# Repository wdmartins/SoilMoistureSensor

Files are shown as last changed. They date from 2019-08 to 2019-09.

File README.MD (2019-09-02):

# Soil Moisture Sensor

This project is aimed to measure vegetable garden soil moisture.

## Features

* MQTT enable: Reports mositure levels using MQTT.

* Deep Sleep: The controllers enters deep sleep mode and wakes up every hour to measure and report the soil mositure. The reporting is done only if the soil moisture show a large change compared to previous measurements or if 4 hours period had elapsed. This reduces power comsumption and allows the device to run on a 18650 3000mAh for up to 2 weeks.

* OTA: Over the air update is enabled by default. In order to do an OTA update, the device shall be awake. Send the following MQTT command so it remains awake the next time it wakes up so OTA can be done:

Topic: /home-assistant/moist/A/request
Payload: 'a'

## Schemmatic

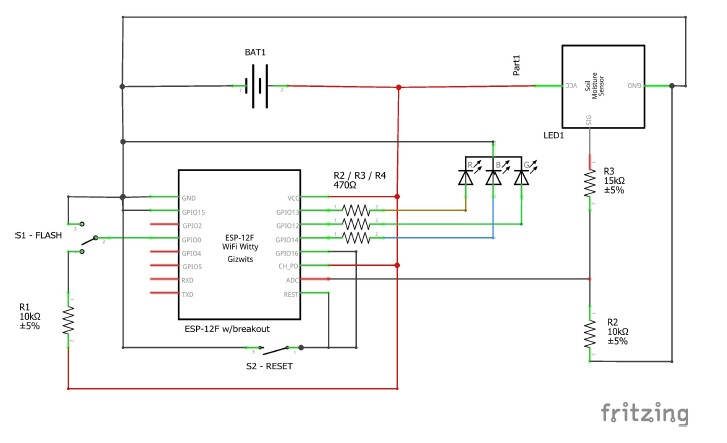
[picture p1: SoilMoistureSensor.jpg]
Soil Moisture Sensor Schemmatics


## Notes

In order to build this software add a file named secret.h at ./include and define the following constant strings:

const char * MQTT_BROKER_ADDRESS = "mqtt-server-address-or-fqdn";

const char * MQTT_USERNAME = "mqtt-user-name";

const char * MQTT_PASSWORD = "mqtt-user-password";

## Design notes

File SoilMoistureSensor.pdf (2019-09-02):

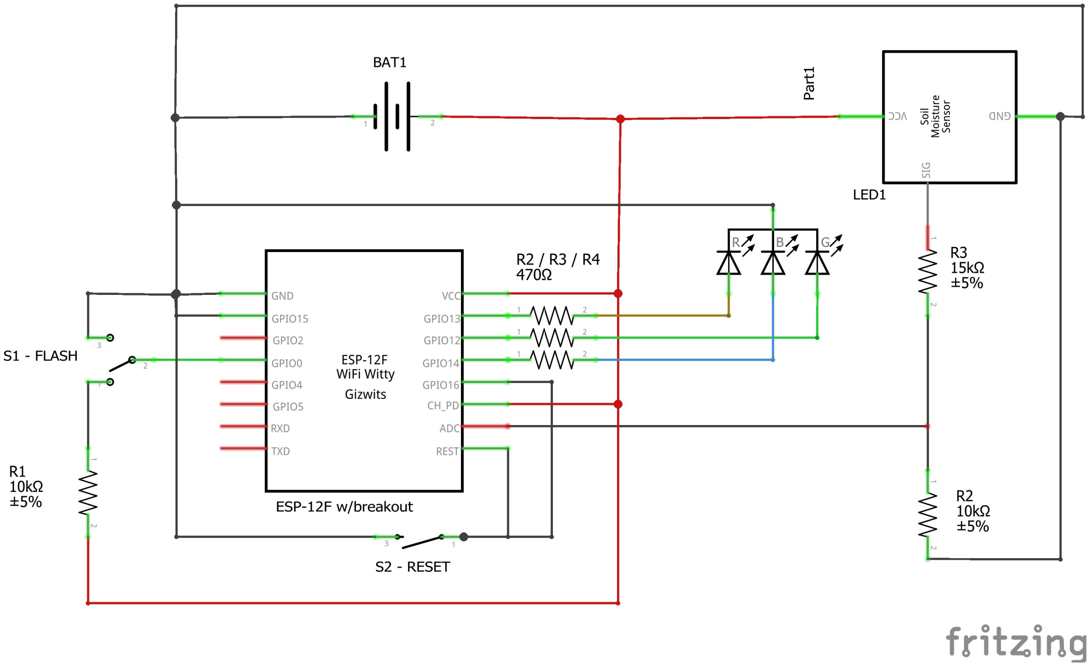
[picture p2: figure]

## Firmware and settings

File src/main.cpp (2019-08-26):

#include <Arduino.h>
#include <EEPROM.h>
#include <WiFiManager.h>
#include <ArduinoOTA.h>
#include <PubSubClient.h>
#include "secret.h"

/*------------------------------------------------------------------------------------*/
/* Constant Definitions                                                               */
/*------------------------------------------------------------------------------------*/
// Access point to configure Wi-Fi
const char* ACCESS_POINT_NAME = "ESP8266";
const char* ACCESS_POINT_PASS = "esp8266";

// MQTT constants
const char * MQTT_CLIENT_PREFIX = "MoistSensor-";
const char * MQTT_IN_TOPIC_RAW = "/home-assistant/moist/%c/request";

// MQTT Moist Client Id. Every Moisture Sensor in the MQTT network must have a different id
const char MQTT_MOIST_CLIENT_ID = 'A';

// MQTT Commands
const char MQTT_CMD_KEEP_AWAKE = 'a';   // Keep awake for OTA update
const char MQTT_CMD_DEEP_SLEEP = 's';   // Go back to deep sleep
const char MQTT_CMD_DEEP_TEST = 't';    // Run hardware test
const char MQTT_CMD_DEEP_RANGE = 'r';   // wet-dry Range set

// MQTT Events
const char * MQTT_REPORT_MOISTURE_RAW = "/home-assistant/moist/%c/moist";
const char * MQTT_REPORT_TEST_ENDED_RAW = "/home-assistant/moist/%c/testended";
const char * MQTT_REPORT_RANGE_RAW = "/home-assistant/moist/%c/range";
const char * MQTT_OTA_READY_RAW = "/home-assistant/moist/%c/otaready";

// Moisture sensor values normalization constants
const uint16_t MAX_SENSOR_VALUE = 600;
const uint16_t MIN_SENSOR_VALUE = 300;
const uint16_t NORM_SENSOR_RANGE = MAX_SENSOR_VALUE - MIN_SENSOR_VALUE;

const uint16_t DRYNESS_LOW = 400;
const uint16_t DRYNESS_HIGH = 500;

// Deep Sleep Period
const uint64_t DEEP_SLEEP_PERIOD_TEST = 20e6;   // 20 seconds
const uint64_t DEEP_SLEEP_PERIOD_PROD = 3600e6; // 1 hour
const uint64_t DEEP_SLEEP_PERIOD = DEEP_SLEEP_PERIOD_PROD;
const uint16_t MAX_SLEEP_PERIOD_WITHOUT_REPORTING = 3;
const uint16_t MAX_PERCENT_POINTS_WITHOUT_REPORTING = 5;

/*------------------------------------------------------------------------------------*/
/* GPIO Definitions                                                                   */
/*------------------------------------------------------------------------------------*/
const uint8_t GPIO_ANALOG_00 = 0;          // ESP8266 NodeMCU A0
const uint8_t GPIO_UNUSED_00 = 0;          // ESP8266 NodeMCU D3
const uint8_t GPIO_UNUSED_01 = 1;          // ESP8266 NodeMUC TX (UART)
const uint8_t GPIO_UNUSED_02 = 2;          // ESP8266 NodeMUC D4 (Boot mode. Do not user for INPUT)
const uint8_t GPIO_UNUSED_03 = 3;          // ESP8266 NodeMCU RX (UART)
const uint8_t GPIO_DISPLAY_SDA = 4;        // ESP8266 NodeMCU D2 (SDA) 
const uint8_t GPIO_DISPLAY_SCL = 5;        // ESP8266 NodeMCU D1 (SCL)
const uint8_t GPIO_UNUSED_06 = 6;          // ESP8266 NodeMCU -+ F M
const uint8_t GPIO_UNUSED_07 = 7;          // ESP8266 NodeMCU  + L E
const uint8_t GPIO_UNUSED_08 = 8;          // ESP8266 NodeMCU  + A M
const uint8_t GPIO_UNUSED_09 = 9;          // ESP8266 NodeMCU  + S O
const uint8_t GPIO_UNUSED_10 = 10;         // ESP8266 NodeMCU  + H R
const uint8_t GPIO_UNUSED_11 = 11;         // ESP8266 NodeMCU -+   Y
const uint8_t GPIO_RGB_LED_GREEN = 12;     // ESP8266 NodeMCU D6
const uint8_t GPIO_RGB_LED_BLUE = 13;      // ESP8266 NodeMCU D7
const uint8_t GPIO_RGB_LED_RED = 14;       // ESP8266 NodeMUC D5
const uint8_t GPIO_UNUSED_15 = 15;         // ESP8266 NodeMCU D8 (Boot from SD Card)
const uint8_t GPIO_UNUSED_16 = 16;         // ESP8266 NodeMCU D0

const uint8_t GPIO_TOO_DRY = GPIO_RGB_LED_RED;
const uint8_t GPIO_MOIST = GPIO_RGB_LED_GREEN;
const uint8_t GPIO_TOO_WET = GPIO_RGB_LED_BLUE;
const uint8_t GPIO_MOIST_SENSOR = GPIO_ANALOG_00;

/*------------------------------------------------------------------------------------*/
/* Forward Declarations                                                               */
/*------------------------------------------------------------------------------------*/
uint8_t calculateMoistPercent(uint16_t dryness);

/*------------------------------------------------------------------------------------*/
/* Global Variables                                                                   */
/*------------------------------------------------------------------------------------*/
// RTC Data Structure
struct {
  uint32_t crc32;
  struct {
    uint16_t lastReadValue;
    uint16_t periodCount;
  } data;
} rtcData;

// WiFi Manager
WiFiManager wifiManager;

// MQTT
WiFiClient espClient;
PubSubClient mqttClient(espClient);

// Prevent Deep Sleep to Allow OTA updates
bool deepSleep = true;

// Default Mositure Range
uint8_t tooWet = calculateMoistPercent(DRYNESS_LOW);
uint8_t tooDry = calculateMoistPercent(DRYNESS_HIGH);

// Prevent reporting in loop
bool rangeReported = false;

char MQTT_IN_TOPIC[64];
char MQTT_REPORT_MOISTURE[64];
char MQTT_REPORT_TEST_ENDED[64];
char MQTT_REPORT_RANGE[64];
char MQTT_OTA_READY[64];

void initMqttTopics(void) {
  sprintf(MQTT_IN_TOPIC, MQTT_IN_TOPIC_RAW, MQTT_MOIST_CLIENT_ID);
  sprintf(MQTT_REPORT_MOISTURE, MQTT_REPORT_MOISTURE_RAW, MQTT_MOIST_CLIENT_ID);
  sprintf(MQTT_REPORT_TEST_ENDED, MQTT_REPORT_TEST_ENDED_RAW, MQTT_MOIST_CLIENT_ID);
  sprintf(MQTT_REPORT_RANGE, MQTT_REPORT_RANGE_RAW, MQTT_MOIST_CLIENT_ID);
  sprintf(MQTT_OTA_READY, MQTT_OTA_READY_RAW, MQTT_MOIST_CLIENT_ID);
}
/*------------------------------------------------------------------------------------*/
/* Global Functions                                                                   */
/*------------------------------------------------------------------------------------*/
// WiFiManager Configuration CallBack
void configModeCallback (WiFiManager *myWiFiManager) {
  Serial.println("[WIFI]: Entered config mode");
  Serial.print("[WIFI]:"); Serial.println(WiFi.softAPIP());
  Serial.printf("[WIFI]: %s", (myWiFiManager->getConfigPortalSSID()).c_str());
}

// Calculate CRC32 to validate RTC stored data
uint32_t calculateCRC32(const uint8_t *data, size_t length) {
  uint32_t crc = 0xffffffff;
  while (length--) {
    uint8_t c = *data++;
    for (uint32_t i = 0x80; i > 0; i >>= 1) {
      bool bit = crc & 0x80000000;
      if (c & i) {
        bit = !bit;
      }
      crc <<= 1;
      if (bit) {
        crc ^= 0x04c11db7;
      }
    }
  }
  return crc;
}

// Save data to RTC storage (Deep Sleep surviving)
void saveRtcData(void) {
  // Update CRC32 of data
  rtcData.crc32 = calculateCRC32((uint8_t*) &rtcData.data, sizeof(rtcData.data));
  // Write struct to RTC memory
  ESP.rtcUserMemoryWrite(0, (uint32_t*) &rtcData, sizeof(rtcData));
}

// Report set moisture range (too wet/too dry) through MQTT
void reportRange(void) {
  char payload[64];
  sprintf(payload, "From: %02u%% to: %02u%%", tooDry, tooWet);
  Serial.printf("[MOIST] Reporting range [%s]", payload);
  mqttClient.publish(MQTT_REPORT_RANGE, payload);
}

// Check is system should stay awake for OTA update
void checkOTA(void) {
  Serial.println("[OTA]: Checking OTA...");
  for (uint8_t i = 0; i < 20; i++) {
    mqttClient.loop();
    delay(100);
  }
  Serial.println("[OTA]: End checking OTA...");
}

// Calculate moisture percentage base on dryness value provide by sensor
uint8_t calculateMoistPercent(uint16_t dryness) {
  // Normalize
  dryness = (dryness > MAX_SENSOR_VALUE ? MAX_SENSOR_VALUE : dryness);
  dryness = (dryness < MIN_SENSOR_VALUE ? MIN_SENSOR_VALUE : dryness);
  uint8_t percent = 100 - (dryness - MIN_SENSOR_VALUE) / (NORM_SENSOR_RANGE / 100);
  return percent;
}

// Run system test
void runTest(void) {
  digitalWrite(GPIO_TOO_DRY, LOW);
  digitalWrite(GPIO_TOO_WET, LOW);
  digitalWrite(GPIO_MOIST, LOW);

  digitalWrite(GPIO_TOO_DRY, HIGH);
  delay(1000);
  digitalWrite(GPIO_TOO_DRY, LOW);
  digitalWrite(GPIO_TOO_WET, HIGH);
  delay(1000);
  digitalWrite(GPIO_TOO_WET, LOW);
  digitalWrite(GPIO_MOIST, HIGH);
  delay(1000);
  digitalWrite(GPIO_MOIST, LOW);

  uint16_t value = analogRead(GPIO_MOIST_SENSOR);
  Serial.printf("[MOIST]: Dryness Read %u\n", value);
}

// Read moisture sensor value
uint16_t readSensor(void) {
  // Read three times and report average
  uint16_t read1 = analogRead(GPIO_MOIST_SENSOR);
  delay(500);
  uint16_t read2 = analogRead(GPIO_MOIST_SENSOR);
  delay(500);
  uint16_t read3 = analogRead(GPIO_MOIST_SENSOR);
  Serial.printf("[MOIST]: Dryness reads: (%u), (%u), (%u)\n", read1, read2, read3);
  return (read1 + read2 + read3) / 3;
}

// Process sensor value
void processSensorRead(uint16_t moistPercent) {
  if (moistPercent <= tooDry) {
    digitalWrite(GPIO_TOO_DRY, HIGH);
  } else if (moistPercent >= tooWet) {
    digitalWrite(GPIO_TOO_WET, HIGH);
  } else {
    digitalWrite(GPIO_MOIST, HIGH);
  }
}

// Report current moisture value through MQTT
void publishMoisture(uint16_t moistPercent) {
  // Report to MQTT broker
  char payload[20];
  sprintf(payload, "%u", moistPercent);
  Serial.printf("[MOIST]: Reporting moisture. Moisture: %s%%\n", payload);
  mqttClient.publish(MQTT_REPORT_MOISTURE, payload);
}

// MQTT Subscribe Callback
void callback(char* topic, byte* payload, uint8_t length) {
  Serial.printf("[MQTT]: Message arrived [%s]\n", topic);
  Serial.print("[MQTT]: Payload (");
  for (uint8_t i=0; i < length; i++) {
    Serial.print((char)payload[i]);
  }
  Serial.println(")");
  switch((char) payload[0]) {
    case MQTT_CMD_KEEP_AWAKE:
      if (deepSleep) {
        deepSleep = false;
      }
      break;
    case MQTT_CMD_DEEP_SLEEP:
      if (!deepSleep) {
        deepSleep = true;
        Serial.println("[MQTT]: Going to sleep now...");
        delay(1000);
        ESP.deepSleep(DEEP_SLEEP_PERIOD);
      }
      break;
    case MQTT_CMD_DEEP_TEST:
      Serial.println("[MQTT]: Start test...");
      runTest();
      mqttClient.publish(MQTT_REPORT_TEST_ENDED, "");
      break;
    case MQTT_CMD_DEEP_RANGE:
      Serial.printf("[MQTT]: Received new Wet-Dry range.");
      char aux[16];
      sprintf(aux, "%c%c", payload[1], payload[2]);
      tooDry = atoi(aux);
      sprintf(aux, "%c%c", payload[3], payload[4]);
      tooWet = atoi(aux);
      reportRange();
      break;
    default: 
      Serial.printf("[MQTT]: Unknown MQTT Command: %c\n", (char) payload[0]);
      break;
  }
}

// MQTT Client reconnection
void reconnect() {
  // Loop until we're reconnected
  while (!mqttClient.connected()) {
    Serial.println("[MQTT]: Attempting MQTT connection...");
    // Create a random client ID
    String clientId = MQTT_CLIENT_PREFIX;
    clientId += String(random(0xffff), HEX);
    // Attempt to connect
    if (mqttClient.connect(clientId.c_str(), MQTT_USERNAME, MQTT_PASSWORD)) {
      Serial.println("[MQTT]: Connected");
      // ... and resubscribe
      mqttClient.subscribe(MQTT_IN_TOPIC);
    } else {
      Serial.printf("[MQTT]: Failed, rc= %d, try again in 5 seconds\n", mqttClient.state());
      // Wait 5 seconds before retrying
      delay(5000);
    }
  }
}

void setup() {
  Serial.begin(115200);
  delay(1000);
  Serial.println("");

  // Check RTC Memory
  if (ESP.rtcUserMemoryRead(0, (uint32_t*) &rtcData, sizeof(rtcData))) {
    uint32_t crcOfData = calculateCRC32((uint8_t*) &rtcData.data, sizeof(rtcData.data));
    Serial.printf("[RTC]: Calculate CRC32: %X\n", crcOfData);
    if (crcOfData != rtcData.crc32) {
      Serial.printf("[RTC]: Store CRC32 (%X) does not match calculated CRC32\n", rtcData.crc32);
      Serial.println("[RTC]: Powering up");
      rtcData.data.periodCount = MAX_SLEEP_PERIOD_WITHOUT_REPORTING;
      rtcData.data.lastReadValue = 0;
    } else {
      Serial.printf("[RTC]: Store CRC32 (%X) matches calculated CRC32\n", rtcData.crc32);
      Serial.println("[RTC]: Waiking up");
      Serial.printf("[RTC]: Stored values: Period = %u, LastRead = %u\n", rtcData.data.periodCount, rtcData.data.lastReadValue);
    }
  }

  // GPIO Setup
  pinMode(GPIO_TOO_DRY, OUTPUT);
  pinMode(GPIO_TOO_WET, OUTPUT);
  pinMode(GPIO_MOIST, OUTPUT);

  runTest();


  // Read moisture sensor and process data
  uint16_t moistPercent = calculateMoistPercent(readSensor());
  if (moistPercent > (rtcData.data.lastReadValue + MAX_PERCENT_POINTS_WITHOUT_REPORTING) ||
      moistPercent < (rtcData.data.lastReadValue - MAX_PERCENT_POINTS_WITHOUT_REPORTING) ||
      rtcData.data.periodCount ++ > MAX_SLEEP_PERIOD_WITHOUT_REPORTING) {
    rtcData.data.periodCount = 0;
    rtcData.data.lastReadValue = moistPercent;
    saveRtcData();
  } else {
    Serial.println("[MOIST]: No reporting needed now. Go back to sleep.");
    rtcData.data.lastReadValue = moistPercent;
    saveRtcData();
    delay(1000);
    ESP.deepSleep(DEEP_SLEEP_PERIOD);
  }

  digitalWrite(GPIO_TOO_DRY, LOW);
  digitalWrite(GPIO_TOO_WET, LOW);
  digitalWrite(GPIO_MOIST, LOW);

  processSensorRead(moistPercent);

  // Instantiate and setup WiFiManager
  // wifiManager.resetSettings(); Uncomment to reset wifi settings
  wifiManager.setAPCallback(configModeCallback);
  if (!wifiManager.autoConnect(ACCESS_POINT_NAME, ACCESS_POINT_PASS)) {
    Serial.println("Failed to connect and hit timeout");
    ESP.reset();
    delay(1000);  
  }

  // Setup MQTT client
  initMqttTopics();
  mqttClient.setServer(MQTT_BROKER_ADDRESS, 1883);
  mqttClient.setCallback(callback);

  // MQTT
  if (!mqttClient.connected()) {
    reconnect();
  }
  mqttClient.publish(MQTT_OTA_READY, "No");

  checkOTA();

  // Config time
  setenv("TZ", "EST5EDT,M3.2.0/02:00:00,M11.1.0/02:00:00", 1);
  configTime(0, 0, "pool.ntp.org");

  // Initialize OTA (Over the air) update
  ArduinoOTA.setHostname(ACCESS_POINT_NAME);
  ArduinoOTA.setPassword(ACCESS_POINT_PASS);

  ArduinoOTA.onStart([]() {
    Serial.println("[OTA]: Start");
  });
  ArduinoOTA.onEnd([]() {
    Serial.println("[OTA]: End");
  });
  ArduinoOTA.onProgress([](uint32_t progress, uint32_t total) {
    Serial.printf("[OTA]: Progress: %u%%\r", (progress / (total / 100)));
  });
  ArduinoOTA.onError([](ota_error_t error) {
    Serial.printf("[OTA]: Error[%u]: ", error);
    if (error == OTA_AUTH_ERROR) Serial.println("[OTA]: Auth Failed");
    else if (error == OTA_BEGIN_ERROR) Serial.println("[OTA]: Begin Failed");
    else if (error == OTA_CONNECT_ERROR) Serial.println("[OTA]: Connect Failed");
    else if (error == OTA_RECEIVE_ERROR) Serial.println("[OTA]: Receive Failed");
    else if (error == OTA_END_ERROR) Serial.println("[OTA]: End Failed");
  });
  ArduinoOTA.begin();
  Serial.println("[OTA]: Ready");

  Serial.printf("[MOIST]: Publishing mositure value (%u)", moistPercent);
  publishMoisture(moistPercent);
  Serial.println("[MOIST]: Going back to sleep");

  delay(1000);
  // Deep Sleep
  if (deepSleep) {
    ESP.deepSleep(DEEP_SLEEP_PERIOD);
  }

}

void loop() {
  if (!deepSleep) {
    // OTA
    ArduinoOTA.handle();

    // MQTT
    if (!mqttClient.connected()) {
      reconnect();
    }
    mqttClient.loop();

    // Indicate ready for OTA update
    digitalWrite(GPIO_MOIST, HIGH);

    // Report current range
    if (!rangeReported) {
      // Report reay for OTA
      mqttClient.publish(MQTT_OTA_READY, "yes");
      reportRange();
      rangeReported = true;
    }
  }
}

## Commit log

2019-06-09 Changed to common cathod RGB LED. Added test command
2019-06-27 Adjust Sensor Values for ESP-12E. Fix GPIO definitions
    [main.cpp]
2019-08-26 Improved Security and Power Use
2019-09-02 Added Schematics
    [MositureSensorLogic.fzz]
